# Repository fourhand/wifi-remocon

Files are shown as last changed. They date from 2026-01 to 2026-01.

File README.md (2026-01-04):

# 에어컨 제어 시스템

## 설치 및 실행

### 1. Python 설치 (필수)

Python이 설치되어 있지 않은 경우:

1. [Python 공식 사이트](https://www.python.org/downloads/)에서 다운로드
2. 설치 시 **"Add Python to PATH"** 옵션을 **반드시 체크**하세요
3. 설치 완료 후 명령 프롬프트를 다시 시작하세요

### 2. 초기 설정 (권장)

가상환경을 생성하고 필요한 패키지를 설치합니다:

```bash
setup.bat
```

또는 단계별로:

```bash
# 가상환경 생성 및 패키지 설치
install-dependencies.bat
```

### 3. 서버 실행

```bash
start-server.bat
```

서버는 자동으로 가상환경을 활성화하고 실행됩니다.

### 가상환경 수동 사용

가상환경을 수동으로 활성화하려면:

```bash
venv\Scripts\activate.bat
```

비활성화하려면:

```bash
deactivate
```

### 4. 웹 브라우저에서 접속

- http://localhost:8000
- http://aircon-controller.local:8000 (mDNS 사용 시)

### 5. Windows 자동 시작 설정 (선택)

부팅할 때 자동으로 서버를 구동하려면 **관리자 권한** PowerShell(또는 명령 프롬프트)에서 아래 스크립트를 실행하세요.

```powershell
cd C:\Users\k\Documents\wifi-remocon
.\register-autostart.bat
```

- Windows 작업 스케줄러에 `WifiRemoconControlServer` 작업이 생성되며, 부팅 후 30초 뒤 `start-server.bat`을 SYSTEM 권한으로 실행합니다.
- 자동 시작을 해제하려면:

```powershell
cd C:\Users\k\Documents\wifi-remocon
.\unregister-autostart.bat
```

작업 상태 확인: `schtasks /Query /TN WifiRemoconControlServer`

## 문제 해결

### Python을 찾을 수 없는 경우

1. Python이 설치되어 있는지 확인: `python --version`
2. Python이 설치되어 있지만 PATH에 없는 경우:
   - `install-dependencies.bat` 또는 `start-server.bat` 실행 시
   - Python 실행 파일 경로를 직접 입력하라는 메시지가 나타납니다
   - 예: `C:\Python39\python.exe` 또는 `C:\Users\사용자명\AppData\Local\Programs\Python\Python39\python.exe`

### 서버가 실행되지 않는 경우

1. 필요한 패키지가 설치되어 있는지 확인: `pip list | findstr fastapi`
2. 포트 8000이 사용 중인지 확인: `netstat -ano | findstr :8000`
3. `start-server.bat`을 실행하여 오류 메시지 확인

### 브라우저에서 접근이 안되는 경우

1. 서버가 실행 중인지 확인
2. 방화벽 설정 확인
3. `http://127.0.0.1:8000`으로 접속 시도
4. 다른 브라우저로 시도

## API 엔드포인트

### 공통
- **Base URL**: `http://localhost:8000`
- **Content-Type**: `application/json`

### 요청 바디 스키마: AcCommand
- **power**: `"on"` | `"off"` (예: `"on"`)
- **mode**: 냉방/난방/제습/송풍/자동 등 장치가 이해하는 문자열 (예: `"cool"`)
- **temp**: 정수 온도 (예: `24`)
- **fan**: 풍량 (예: `"low"`, `"mid"`, `"high"`)
- **swing**: 풍향 (예: `"on"`, `"off"` 등)

필드는 모두 선택이며, 전달된 필드만 장치에 반영됩니다.

---

### GET /devices
- **설명**: 현재 발견된 장치 목록 조회
- **응답 예시**
```json
[
  {
    "id": "ac-01",
    "ip": "192.168.0.12",
    "port": 80,
    "last_seen": 1733980000.123
  }
]
```

### GET /devices/{device_id}/health
- **설명**: 특정 장치 Health 체크
- **응답 예시**
```json
{
  "device": "ac-01",
  "health": { "ok": true, "status_code": 200 }
}
```

### GET /devices/{device_id}/ac/state
- **설명**: 특정 장치의 현재 상태 조회
- **응답 예시**
```json
{
  "device": "ac-01",
  "ok": true,
  "state": {
    "power": "on",
    "mode": "cool",
    "temp": 24,
    "fan": "mid",
    "swing": "off"
  }
}
```

### GET /devices/status
- **설명**: 모든 장치의 상태를 한 번에 조회
- **응답 예시**
```json
[
  {
    "id": "ac-01",
    "ip": "192.168.0.12",
    "port": 80,
    "health": { "ok": true, "status_code": 200 },
    "state": {
      "power": "on",
      "mode": "cool",
      "temp": 24,
      "fan": "mid",
      "swing": "off"
    }
  }
]
```

### POST /devices/{device_id}/ac/set
- **설명**: 특정 장치 제어
- **바디**: `AcCommand`
- **응답 예시**
```json
{
  "device": "ac-01",
  "ip": "192.168.0.12",
  "params": { "power": "on", "mode": "cool", "temp": 24 },
  "result": {
    "ok": true,
    "status_code": 200,
    "attempts": 7,
    "all_results": [
      { "ok": true, "status_code": 200, "attempt": 1 }
      // ... 반복 전송 결과
    ]
  }
}
```

### POST /devices/control
- **설명**: 여러 장치를 한 번에 제어. 서버에서 병렬 처리 후 장치별 결과와 요약을 반환
- **바디**
```json
{
  "device_ids": ["ac-01", "ac-02"],
  "command": { "power": "on", "mode": "hot", "temp": 30 }
}
```
- **응답 예시**
```json
{
  "command": { "power": "on", "mode": "hot", "temp": 30 },
  "requested_ids": ["ac-01", "ac-02"],
  "target_ids": ["ac-01"],
  "missing": ["ac-02"],
  "summary": {
    "requested": 2,
    "attempted": 1,
    "succeeded": 1,
    "failed": 0,
    "missing": 1
  },
  "results": {
    "ac-01": { "ok": true, "status_code": 200, "attempts": 7, "all_results": [/* ... */] }
  }
}
```

### POST /all/on
- **설명**: 모든 장치를 켬. 기본값은 `{"power":"on","mode":"cool","temp":24}` 이며, 바디로 전달한 필드로 덮어쓸 수 있음
- **바디(선택)**: `AcCommand`
- **응답**: 각 장치별 결과 맵
```json
{
  "command": { "power": "on", "mode": "cool", "temp": 24 },
  "results": {
    "ac-01": { "ok": true, "status_code": 200, "attempts": 7, "all_results": [/*...*/] }
  }
}
```

### POST /all/off
- **설명**: 모든 장치를 끔
- **바디**: 없음
- **응답**: `/all/on`과 동일 형태로 각 장치별 결과 반환

### POST /webhook
- **설명**: 배포 스크립트(`deploy.sh`) 실행 트리거. 비동기로 실행되며, 서버는 즉시 응답.
- **응답 예시**
```json
{ "ok": true, "message": "Deployment started" }
```

---

### cURL 예시
```bash
# 장치 목록
curl -s http://localhost:8000/devices

# 특정 장치 상태
curl -s http://localhost:8000/devices/ac-01/ac/state

# 특정 장치 제어 (켜기)
curl -s -X POST http://localhost:8000/devices/ac-01/ac/set \
  -H "Content-Type: application/json" \
  -d '{"power":"on","mode":"cool","temp":24}'

# 모두 끄기
curl -s -X POST http://localhost:8000/all/off
```

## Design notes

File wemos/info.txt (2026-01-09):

https://www.tindie.com/products/mostlyrobots/wemos-d1-mini-pro-16mb-with-external-antenna/

This Wemos D1 Mini Pro ESP8266 Internet of Things Development Board has the same footprint and size as a standard Wemos D1 Mini, but it has both a built-in ceramic antenna or an external antenna (needs soldering skills). This gives it better WiFi range than a normal PCB antenna. Good for projects in the garden or far from an access point.

Specifications:

Dimensions: 1" x 1.3" x 0.063" (25.4mm x 33.0 x 1.6mm)
11 digital IO, interrupt/PWM/I2C/one-wire supported on 0.1" headers
1 analog input (3.2V max)
Micro USB connection with onboard CH340 serial IO chip
Compatible with MicroPython, Arduino, nodemcu
3.3v device, can be powered by USB 5v
16M bytes Flash
Clock Speed : 80/160MHz
Onboard chip antenna
Selectable uFL connector for external antenna (requires soldering)
More details here: https://docs.wemos.cc/en/latest/d1/d1_mini.html

These tiny IoT development boards are perfect for home automations projects. They can be flashed with the open source Tasmota firmware to use Home Automation applications of MQTT messages to control devices and read sensors.

The board comes with:

Two 8 way pin headers
Two 8 way sockets
Two 8 way extension sockets
uFL to SMA pig tail
SMA antenna
** PLEASE NOTE: By default, the on-board ceramic chip antenna is used by the ESP8266. The uFL connector can be used instead by moving an 0603 surface mount zero ohm resistor. If you do not have a capability to do this, I can move it for you before I send it to you. Select the option in the side bar when ordering.

This board is compatible with my 4 Channel MOSFET Shield for Wemos D1 Mini ESP8266 and I use it in my home automation projects.

To read more about the projects I use these boards for read my blog : https://blog.mostlyrobots.net/

Automatic Garden Watering to control four water solenoids connected to garden hoses.
Immersion Heater Controller to control 2 high current relays to switch two 3kW hot water immersion heaters.
Automatic plant Pot Watering to control a small peristaltic pump to water pot plants based on moisture reading from a capacitive moisture sensor.

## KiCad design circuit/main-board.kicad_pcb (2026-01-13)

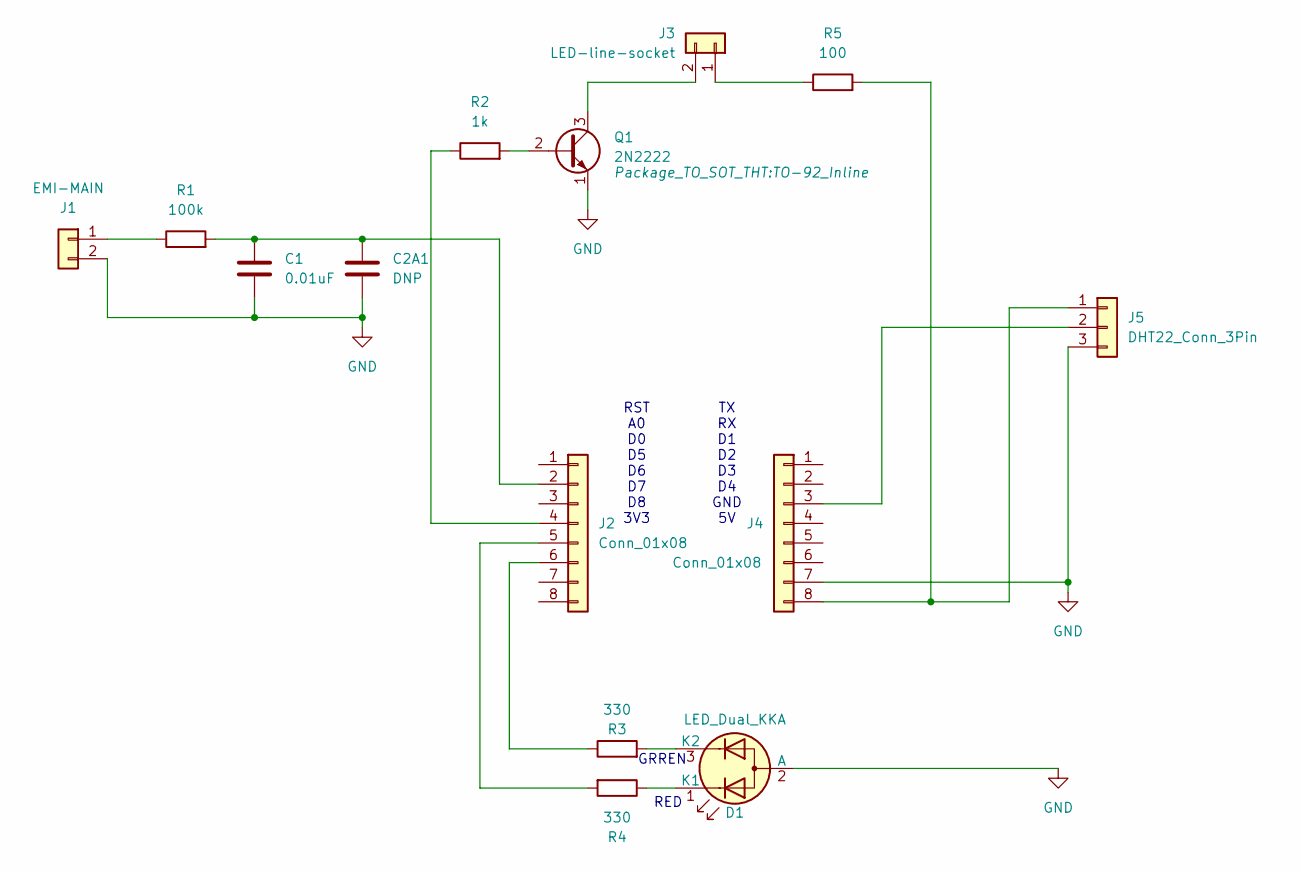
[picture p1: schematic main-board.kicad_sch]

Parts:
C1: 0.01uF; C_Disc_D5.0mm_W2.5mm_P2.50mm
C2A1: DNP; C_Disc_D5.0mm_W2.5mm_P2.50mm
D1: LED_Dual_KKA; LED_D5.0mm-3
J1: EMI-MAIN; U.FL_Hirose_U.FL-R-SMT-1_Vertical
J2, J4: Conn_01x08; PinHeader_1x08_P2.54mm_Vertical
J3: LED-line-socket; JST_PH_B2B-PH-K_1x02_P2.00mm_Vertical
J5: DHT22_Conn_3Pin; PinHeader_1x03_P2.54mm_Vertical
Q1: 2N2222; TO-92_Inline
R1: 100k; R_Axial_DIN0204_L3.6mm_D1.6mm_P5.08mm_Horizontal
R2: 1k; R_Axial_DIN0204_L3.6mm_D1.6mm_P5.08mm_Horizontal
R3, R4: 330; R_Axial_DIN0204_L3.6mm_D1.6mm_P5.08mm_Horizontal
R5: 100; R_Axial_DIN0204_L3.6mm_D1.6mm_P5.08mm_Horizontal

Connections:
GND: C1.2, C2A1.2, D1.2 (A), J1.2 (GND), J4.7, J5.3 (GND), Q1.1 (E)
unnamed: D1.1 (K1), R4.1
unnamed: D1.3 (K2), R3.2
unnamed: J1.1 (EMI_SIG), R1.1
unnamed: C1.1, C2A1.1, J2.2, R1.2
unnamed: J2.4, R2.1
unnamed: J2.5, R4.2
unnamed: J2.6, R3.1
unnamed: J3.1 (IR_LED+), R5.1
unnamed: J3.2 (IR_LED-), Q1.3 (C)
unnamed: J4.3, J5.2 (DATA)
unnamed: J4.8, J5.1 (VCC), R5.2
unnamed: Q1.2 (B), R2.2

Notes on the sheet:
TX RX D1 D2 D3 D4 GND 5V
RST A0 D0 D5 D6 D7 D8 3V3
GRREN
RED

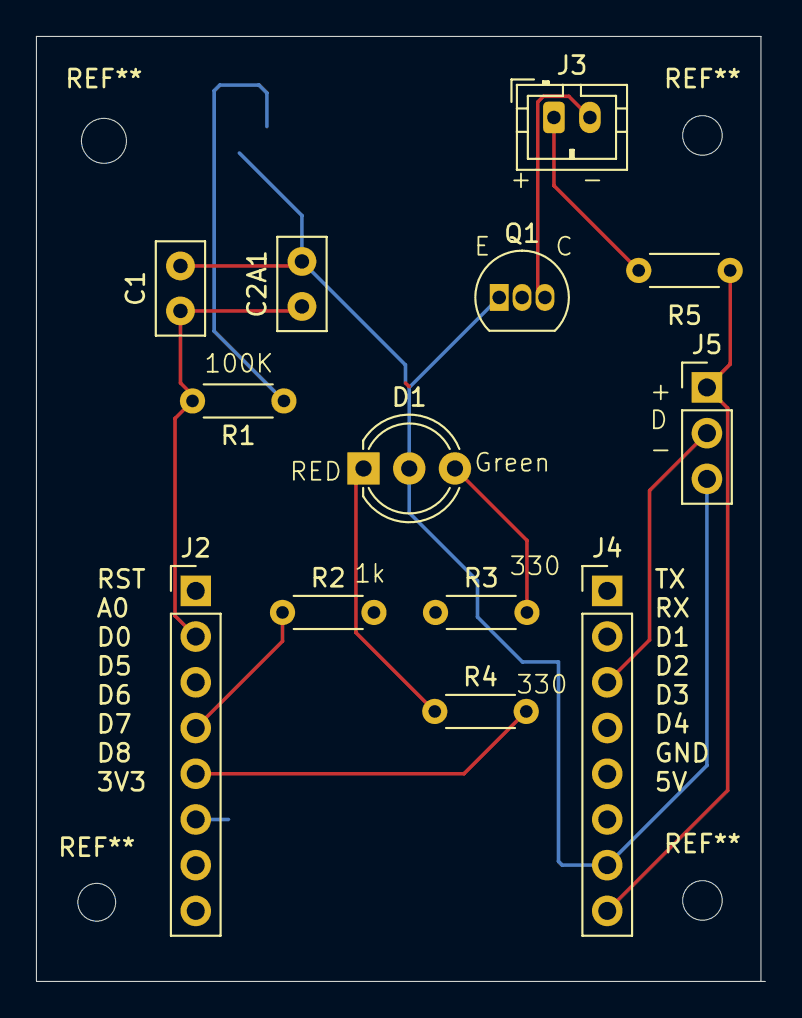
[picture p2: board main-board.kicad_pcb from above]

Board: 4 copper layers, 40.5 x 52.5 mm, 14 parts (1 on the bottom side), 13 nets.

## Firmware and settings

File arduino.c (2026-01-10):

// ---------------------------
// Wi-Fi 설정
// ---------------------------
// const char* SSID = "kyeyoulddd";
// const char* PASS = "000000d750&&";
//const char* SSID = "fourhand_2g";
//const char* PASS = "lyb_99028386";
const char* SSID = "ydch-4 studio 2.4";
const char* PASS = "a1234567890";
// ---------------------------
// 라이브러리
// ---------------------------
#include <ESP.h>
#include <ESP8266WiFi.h>
#include <ESP8266WebServer.h>
#include <ESP8266mDNS.h>
#include <ESP8266HTTPClient.h>
#include <IRremoteESP8266.h>
#include <IRsend.h>
#include <ir_Samsung.h>
#include <DHT.h>
#include <WiFiUdp.h>
#include <EEPROM.h>

// ---------------------------
// 기본 설정
// ---------------------------
static const char* HOST = "f4-ac-01";
static const uint16_t HTTP_PORT = 80;
static const uint16_t UDP_PORT  = 4210;
static const unsigned long MDNS_ANNOUNCE_MS = 120000;
static const unsigned long WIFI_RETRY_INTERVAL_MS = 5000;    // 재연결 간 최소 대기(5초)
static const unsigned long WIFI_CONNECT_TIMEOUT_MS = 120000;  // 초기/재연결 대기 한계(120초)

#define ENABLE_HEARTBEAT 0
// SW WDT: 브로드캐스트(디스커버)가 일정 시간(5분) 들어오지 않으면 리셋
static const unsigned long SW_WDT_DISCOVER_TIMEOUT_MS = 5UL * 60UL * 1000UL;

unsigned long g_lastMdnsAnnounce = 0;
unsigned long g_lastWifiRetryMs = 0;
unsigned long g_lastDiscoverMs = 0;

// IR / LED 핀
#define IR_PIN 14  // D5
#define LED_G 13   // D7
#define LED_R 12   // D6

// DHT22
#define DHTPIN 5   // D1
#define DHTTYPE DHT22
DHT dht(DHTPIN, DHTTYPE);

float g_lastTempC = NAN;
unsigned long g_lastDhtMs = 0;

// IR 송신 표시 타이머(2초)
unsigned long g_irLedUntilMs = 0;

// 서버 명령 수신 표시 타이머(1초) ★
unsigned long g_preSignalUntilMs = 0;

// 최근 브로드캐스트 송신자(백엔드)로 상태 푸시 스케줄링
IPAddress g_backendIp;
uint16_t  g_backendPort = 0;
bool      g_statusPushPending = false;
unsigned long g_statusPushDueMs = 0;
static const uint16_t BACKEND_HTTP_PORT_DEFAULT = 8000;
uint16_t g_backendHttpPort = BACKEND_HTTP_PORT_DEFAULT;

// ---------------------------
// AC 상태 저장
// ---------------------------
bool    st_power = true;
uint8_t st_mode  = kSamsungAcCool;
uint8_t st_temp  = 24;
uint8_t st_fan   = kSamsungAcFanAuto;
bool    st_swing = false;

// ---------------------------
ESP8266WebServer server(HTTP_PORT);
IRSamsungAc ac(IR_PIN);
WiFiUDP udp;

// ---------------------------
// EEPROM 상태 저장/복원
// ---------------------------
#define EEPROM_SIZE 64
#define EEPROM_ADDR 0

static const uint32_t STATE_MAGIC = 0x41435354; // 'ACST'
static const uint8_t  STATE_VER   = 1;

struct PersistState {
  uint32_t magic;
  uint8_t  version;
  uint8_t  power;   // 0/1
  uint8_t  mode;    // kSamsungAcCool / kSamsungAcHeat
  uint8_t  temp;    // 16..30
  uint8_t  fan;     // auto/low/med/high
  uint8_t  swing;   // 0/1
  uint8_t  checksum;
};

inline uint8_t calcChecksum(const PersistState& s) {
  uint16_t sum = 0;
  sum += (uint8_t)(s.magic & 0xFF);
  sum += (uint8_t)((s.magic >> 8) & 0xFF);
  sum += (uint8_t)((s.magic >> 16) & 0xFF);
  sum += (uint8_t)((s.magic >> 24) & 0xFF);
  sum += s.version;
  sum += s.power;
  sum += s.mode;
  sum += s.temp;
  sum += s.fan;
  sum += s.swing;
  return (uint8_t)(sum & 0xFF);
}

bool isValidRanges(const PersistState& s) {
  bool modeOk = (s.mode == kSamsungAcCool || s.mode == kSamsungAcHeat);
  bool tempOk = (s.temp >= 16 && s.temp <= 30);
  bool fanOk  = (s.fan == kSamsungAcFanAuto ||
                 s.fan == kSamsungAcFanLow  ||
                 s.fan == kSamsungAcFanMed  ||
                 s.fan == kSamsungAcFanHigh);
  return modeOk && tempOk && fanOk;
}

void saveStateToEeprom() {
  PersistState p;
  p.magic   = STATE_MAGIC;
  p.version = STATE_VER;
  p.power   = st_power ? 1 : 0;
  p.mode    = st_mode;
  p.temp    = st_temp;
  p.fan     = st_fan;
  p.swing   = st_swing ? 1 : 0;
  p.checksum = 0;
  p.checksum = calcChecksum(p);

  EEPROM.begin(EEPROM_SIZE);
  EEPROM.put(EEPROM_ADDR, p);
  EEPROM.commit();
}

void loadStateFromEeprom() {
  EEPROM.begin(EEPROM_SIZE);
  PersistState p;
  EEPROM.get(EEPROM_ADDR, p);
  if (p.magic == STATE_MAGIC &&
      p.version == STATE_VER &&
      p.checksum == calcChecksum(p) &&
      isValidRanges(p)) {
    st_power = (p.power != 0);
    st_mode  = p.mode;
    st_temp  = p.temp;
    st_fan   = p.fan;
    st_swing = (p.swing != 0);
  } else {
    // 초기 상태(유효 저장 없음) → 현재 기본값을 저장해 다음 부팅부터 유지
    saveStateToEeprom();
  }
}

// ---------------------------
// CORS 헬퍼
// ---------------------------
inline void addCORS() {
  server.sendHeader("Access-Control-Allow-Origin", "*");
  server.sendHeader("Access-Control-Allow-Methods", "GET, OPTIONS");
  server.sendHeader("Access-Control-Allow-Headers", "Content-Type, Accept, Origin");
}

// LED 제어
inline void setLed(bool g_on, bool r_on) {
  digitalWrite(LED_G, g_on ? HIGH : LOW);
  digitalWrite(LED_R, r_on ? HIGH : LOW);
}

// ---------------------------
// LED 우선순위 처리
// ---------------------------
// 1) IR 송신 → 노란색(G+R)
// 2) 서버 명령 수신 → 빨강만
// 3) WiFi 상태(Green/Red)
void updateStatusLeds() {
  unsigned long now = millis();

  // IR 송신중 (2초) => Yellow
  if (now < g_irLedUntilMs) {
    setLed(true, true);
    return;
  }

  // 서버 명령 수신 => Red ON (1초)
  if (now < g_preSignalUntilMs) {
    setLed(false, true);
    return;
  }

  // WiFi 상태
  bool ok = (WiFi.status() == WL_CONNECTED);
  setLed(ok, !ok);
}

// ---------------------------
// IR 송신
// ---------------------------
void applyAndSend() {
  Serial.println("\n=== applyAndSend() ===");

  // IR 송신 표시 (2초)
  g_irLedUntilMs = millis() + 2000;
  updateStatusLeds();

  if (st_power) ac.on(); else ac.off();
  ac.setMode(st_mode);
  ac.setTemp(st_temp);
  ac.setFan(st_fan);
  ac.setSwing(st_swing);

  // 백그라운드 작업에 CPU 양보
  yield();
  ac.send();
  yield();

  Serial.println(">>> IR signal sent.\n");
}

// ---------------------------
// 온도 갱신
// ---------------------------
void updateDhtIfNeeded() {
  unsigned long now = millis();
  if (now - g_lastDhtMs < 2500) return;
  g_lastDhtMs = now;

  float t = dht.readTemperature();
  if (!isnan(t)) g_lastTempC = t;
}

// ---------------------------
// JSON 응답
// ---------------------------
String stateJson() {
  updateDhtIfNeeded();
  String j = "{";
  j += "\"power\":" + String(st_power ? "true" : "false") + ",";
  j += "\"mode\":\"" + String(st_mode == kSamsungAcHeat ? "hot" : "cool") + "\",";
  j += "\"temp\":" + String(st_temp) + ",";
  j += "\"fan\":\"";
  j += (st_fan == kSamsungAcFanLow ? "low" :
        st_fan == kSamsungAcFanMed ? "medium" :
        st_fan == kSamsungAcFanHigh ? "high" : "auto");
  j += "\",";
  j += "\"swing\":" + String(st_swing ? "true" : "false") + ",";
  j += "\"room_temp\":" + (isnan(g_lastTempC) ? "null" : String(g_lastTempC, 1));
  j += "}";
  return j;
}

String netJson() {
  String j = "{";
  j += "\"host\":\"" + String(HOST) + "\",";
  j += "\"domain\":\"" + String(HOST) + ".local" + "\",";
  j += "\"ssid\":\"" + WiFi.SSID() + "\",";
  j += "\"ip\":\"" + WiFi.localIP().toString() + "\",";
  j += "\"rssi\":" + String(WiFi.RSSI());
  j += "}";
  return j;
}

// ---------------------------
// 상태 푸시 (UDP 유니캐스트, 브로드캐스트 질의에 대한 별도 푸시)
// ---------------------------
void pushStatusToBackend() {
  if (!g_statusPushPending) return;
  unsigned long now = millis();
  if ((long)(now - g_statusPushDueMs) < 0) return;
  g_statusPushPending = false;

  String payload = String("{\"id\":\"") + HOST +
                   "\",\"domain\":\"" + HOST + ".local" +
                   "\",\"ip\":\"" + WiFi.localIP().toString() +
                   "\",\"port\":" + HTTP_PORT +
                   ",\"state\":" + stateJson() +
                   "}";
  // HTTP PUT로 백엔드에 유니캐스트 전송
  WiFiClient client;
  HTTPClient http;
  String url = String("http://") + g_backendIp.toString() + ":" + String(g_backendHttpPort) + "/devices/put_status";
  if (http.begin(client, url)) {
    http.addHeader("Content-Type", "application/json");
    int code = http.POST(payload);
    (void)code;
    http.end();
  }
  yield();
}

// ---------------------------
// HTTP 핸들러
// ---------------------------
void handleOptions() { addCORS(); server.send(204, "text/plain", ""); }

void handleSet() {
  addCORS();

  // 서버 신호 수신 → Red 1초
  g_preSignalUntilMs = millis() + 1000;
  updateStatusLeds();

  if (server.hasArg("power")) {
    String v = server.arg("power");
    st_power = (v == "on" || v == "1" || v == "true");
  }
  if (server.hasArg("mode")) {
    String m = server.arg("mode");
    st_mode = (m == "hot") ? kSamsungAcHeat : kSamsungAcCool;
  }
  if (server.hasArg("temp")) {
    int t = server.arg("temp").toInt();
    if (t >= 16 && t <= 30) st_temp = t;
  }
  if (server.hasArg("fan")) {
    String f = server.arg("fan");
    if      (f == "auto")   st_fan = kSamsungAcFanAuto;
    else if (f == "low")    st_fan = kSamsungAcFanLow;
    else if (f == "medium") st_fan = kSamsungAcFanMed;
    else if (f == "high")   st_fan = kSamsungAcFanHigh;
  }
  if (server.hasArg("swing")) {
    String s = server.arg("swing");
    st_swing = (s == "on" || s == "1" || s == "true");
  }

  // 상태 변경 저장
  saveStateToEeprom();

  applyAndSend();
  server.send(200, "application/json", stateJson());
}

void handleState()   { addCORS(); server.send(200, "application/json", stateJson()); }
void handleHealth()  { addCORS(); server.send(200, "application/json", "{\"ok\":true}"); }
void handleNetInfo() { addCORS(); server.send(200, "application/json", netJson()); }

void handleNotFound() {
  if (server.method() == HTTP_OPTIONS) return handleOptions();
  addCORS();
  server.send(404, "application/json", "{\"error\":\"not found\"}");
}

// ---------------------------
// WiFi + mDNS
// ---------------------------
void connectWiFi(bool waitUntilConnected = true) {
  WiFi.mode(WIFI_STA);
  WiFi.persistent(false);
  WiFi.hostname(HOST);
  WiFi.setSleepMode(WIFI_NONE_SLEEP);

  WiFi.begin(SSID, PASS);
  Serial.print(waitUntilConnected ? "Connecting" : "Reconnecting");

  unsigned long startWait = millis();
  while (waitUntilConnected && WiFi.status() != WL_CONNECTED) {
    delay(300);
    Serial.print(".");
    // WiFi 스택 유지
    yield();
    if ((long)(millis() - startWait) >= (long)WIFI_CONNECT_TIMEOUT_MS) {
      Serial.println("\n[WiFi] 연결 대기 시간 초과. 장치를 재부팅합니다.");
      delay(500);
      ESP.restart();
    }
  }
  if (WiFi.status() == WL_CONNECTED) {
    Serial.println("\nConnected: " + WiFi.localIP().toString());
    g_lastWifiRetryMs = millis();
  } else {
    Serial.println("\n[WiFi] 연결 대기 중...");
  }
}

void startMDNS() {
  if (MDNS.begin(HOST)) {
    MDNS.addService("http", "tcp", HTTP_PORT);
    MDNS.announce();
    g_lastMdnsAnnounce = millis();
  }
}

// ---------------------------
// Heartbeat
// ---------------------------
#if ENABLE_HEARTBEAT
static const unsigned long HEARTBEAT_MIN_MS = 30000;  // 30s
static const unsigned long HEARTBEAT_MAX_MS = 120000; // 120s
unsigned long g_nextHeartbeatMs = 0;

inline unsigned long nextHeartbeatDelayMs() {
  return (unsigned long)random(HEARTBEAT_MIN_MS, HEARTBEAT_MAX_MS + 1);
}

void scheduleNextHeartbeat(unsigned long now) {
  g_nextHeartbeatMs = now + nextHeartbeatDelayMs();
}

void sendHeartbeatIfDue() {
  unsigned long now = millis();
  if ((long)(now - g_nextHeartbeatMs) < 0) return;

  String p = String("{\"id\":\"") + HOST +
             "\",\"ip\":\"" + WiFi.localIP().toString() +
             "\",\"port\":" + HTTP_PORT + "}";

  udp.beginPacket(IPAddress(255,255,255,255), UDP_PORT);
  udp.write((const uint8_t*)p.c_str(), p.length());
  udp.endPacket();

  yield();
  scheduleNextHeartbeat(now);
}
#endif

// ---------------------------
// Discover 응답
// ---------------------------
void handleUdpQuery() {
  int n = udp.parsePacket();
  if (n <= 0) return;

  char buf[96];
  if (n > 95) n = 95;
  int len = udp.read(buf, n);
  buf[len] = 0;

  String q = String(buf);
  q.trim();
  String qLower = q; qLower.toLowerCase();
  String hostLower = String(HOST); hostLower.toLowerCase();

  bool match = (qLower == "discover" ||
                qLower == "whois *" ||
                qLower == ("whois " + hostLower));

  if (!match) return;

  // 마지막 디스커버 수신 시각 갱신 (SW WDT 피드)
  g_lastDiscoverMs = millis();

  // 즉시 큰 payload로 응답하지 않고, 약간의 지터 후 상태를 유니캐스트로 푸시
  g_backendIp = udp.remoteIP();
  g_backendPort = udp.remotePort();
  // discover 페이로드에서 http_port 힌트가 있으면 반영 (JSON 가벼운 파싱)
  int hp = q.indexOf("\"http_port\"");
  if (hp >= 0) {
    int c = q.indexOf(':', hp);
    if (c >= 0) {
      int end = q.indexOf(',', c + 1);
      if (end < 0) end = q.indexOf('}', c + 1);
      if (end < 0) end = q.length();
      String num = q.substring(c + 1, end);
      num.trim();
      int port = num.toInt();
      if (port > 0 && port < 65536) g_backendHttpPort = (uint16_t)port;
    }
  } else {
    g_backendHttpPort = BACKEND_HTTP_PORT_DEFAULT;
  }
  // 50~300ms 랜덤 지연으로 동시 충돌 완화
  unsigned long jitter = (unsigned long)random(50, 301);
  g_statusPushDueMs = millis() + jitter;
  g_statusPushPending = true;
  yield();
}

// ---------------------------
// Setup
// ---------------------------
void setup() {
  Serial.begin(115200);
  ac.begin();

  pinMode(LED_R, OUTPUT);
  pinMode(LED_G, OUTPUT);

  setLed(false, true);  // 부팅 시 RED

  // 랜덤 지터용 시드 초기화
  randomSeed(ESP.getChipId() ^ micros());

  dht.begin();
  // 부팅 시 저장된 상태 복원 (없으면 현재 기본값을 초기 저장)
  loadStateFromEeprom();
  connectWiFi();
  updateStatusLeds();
  // SW WDT 초기화(부팅 시점)
  g_lastDiscoverMs = millis();

  udp.begin(UDP_PORT);
  startMDNS();

  server.on("/health",   HTTP_GET,     handleHealth);
  server.on("/ac/set",   HTTP_GET,     handleSet);
  server.on("/ac/set",   HTTP_OPTIONS, handleOptions);
  server.on("/ac/state", HTTP_GET,     handleState);
  server.on("/net/info", HTTP_GET,     handleNetInfo);
  server.onNotFound(handleNotFound);

  server.begin();

#if ENABLE_HEARTBEAT
  // 랜덤 시드 초기화 및 첫 하트비트 스케줄
  randomSeed(ESP.getChipId() ^ micros());
  scheduleNextHeartbeat(millis());
#endif
}

// ---------------------------
// Loop
// ---------------------------
void loop() {
  // Wi-Fi 연결 유지
  if (WiFi.status() != WL_CONNECTED) {
    unsigned long now = millis();
    if ((long)(now - g_lastWifiRetryMs) >= (long)WIFI_RETRY_INTERVAL_MS) {
      Serial.println("[WiFi] Connection lost. Attempting to reconnect...");
      g_lastWifiRetryMs = now;
      setLed(false, true);
      WiFi.disconnect();
      delay(100);
      connectWiFi();
      // 재연결 중에도 다른 작업을 살짝 쉼
      yield();
    }
  }

  server.handleClient();
  MDNS.update();

  if (millis() - g_lastMdnsAnnounce >= MDNS_ANNOUNCE_MS) {
    MDNS.announce();
    g_lastMdnsAnnounce = millis();
  }

  updateDhtIfNeeded();
#if ENABLE_HEARTBEAT
  sendHeartbeatIfDue();
#endif
  handleUdpQuery();
  // 브로드캐스트 질의 수신 후 상태 푸시 스케줄 처리
  pushStatusToBackend();

  // HW WDT feed (안전차원)
  ESP.wdtFeed();

  // SW WDT: 5분간 discover 없으면 재시작 (연결 여부 무관, 필요시 조건 추가 가능)
  if (millis() - g_lastDiscoverMs > SW_WDT_DISCOVER_TIMEOUT_MS) {
    Serial.println("[SW-WDT] No broadcast discover for 5 minutes. Restarting...");
    delay(200);
    ESP.restart();
  }

  static uint32_t last = 0;
  if (millis() - last > 100) {
    last = millis();
    updateStatusLeds();
  }

  yield();
}

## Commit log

2025-12-12 에어콘 버튼위치 변경 배포기능 추가
2025-12-12 feat: 전체 제어 병렬화, UI 페이저/테마/가독성 개선 및 버튼 안전영역 처리 서버(control-server.py) 전체 제어 병렬 처리: /all/on, /all/off 내부 전송을 스레드 병렬화하고 per-device 타임아웃 추가 배치 제어 엔드포인트 추가: POST /devices/batch/ac/set (선택된 여러 장치 병렬 전송) 서버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
2025-12-12 예약기능 작업중
    백엔드
    SQLite 기반 예약 스케줄(1~7) 도입: 전원/모드/온도 + 1회/매일/매주 + 시작/종료 시각.
    API 추가: GET /schedules(목록), PUT /schedules/{sid}(업데이트).
    1분 주기 스케줄러: 시작/종료 시각에 맞춰 전체 제어, 5분간 매분 재전송으로 신뢰성 강화.
    1회 예약은 종료(OFF) 수행 후 자동 비활성화.
    DB 손상 대응: 무결성 검사 실패 시 자동 백업/재생성, 런타임 오류 시 복구 후 계속 동작.
    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
2025-12-12 feat: 예약(7개) + SQLite/CRUD + 1분 스케줄러(5분 재전송) + 예약 UI/시간설정 + all-off 개선
2025-12-12 동작 로그
2025-12-13 update.sh에 git pull → 서비스 재시작 로직 일원화 서버의 배포 트리거도 update.sh 사용으로 전환
2025-12-13 schedule-list.sh 추가
2025-12-13 스캐쥴에 Power 필드없에고 status.sh에 현재온도 값 추가
2025-12-13 요일명 수정
2025-12-13 all-on.sh all-off.sh 추가
2025-12-13 모듈별 정보 받은 시간 표시
2025-12-27 backend: add POST/PUT /devices/put_status ingest and GET /devices/get_status; switch discovery to 30s with http_port hint; cache-based health; client: reduce polling pending; firmware: unicast status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
    [arduino.c]
2025-12-27 schedules: add start_date/end_date, migrate schema, accept in API, update scheduler and summary; GET /devices/get_status alias /devices/status
2025-12-27 backend: retry on failure for device commands (AC_SEND_ATTEMPTS, AC_SEND_INTERVAL_SEC with exponential backoff/jitter)
2025-12-27 web(schedule): reorganize modal into two rows (시작일 시각 / 종요일 시각); dates always visible; weekly shows weekday row
2025-12-27 web(schedule): when schedule panel open, selecting device or 전체선택 switches back to control panel
2025-12-27 web: mark all devices with IP as pending on 전체 켜기/끄기 (was only those with room_temp), fixes UX where 특정 장치만 비활성화 보이던 문제
2026-01-09 esp8266: add cooperative serviceTick(); make WiFi connect non-blocking with timeout; improve reconnect flow (reconnect() first, then async begin) and call serviceTick during waits to prevent stalls
    [emi-board-B_Cu.gbr, emi-board-B_Mask.gbr, emi-board-B_Paste.gbr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]
2026-01-10 wdt: add SW watchdog (restart if no broadcast for 5m); feed HW WDT in loop; track last discover time
2026-01-13 PCB 작업
    [emi-board-B_Cu.gbr, emi-board-B_Mask.gbr, emi-board-B_Paste.gbr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]
2026-02-08 schedule(weekly): clear date fields when switching to weekly (DB) and ignore dates in scheduler; UI hides date inputs for weekly and sends nulls
